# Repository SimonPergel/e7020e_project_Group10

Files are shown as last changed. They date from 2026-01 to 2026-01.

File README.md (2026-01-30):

# e7020e_project

# TOTP with automatic password input

## Members

- Gabriel Axheim Gustafsson (gabaxh-2@student.ltu.se)
- Patrik Wall (walpat-1@student.ltu.se)
- Simon Pergel (isoepe-1@student.ltu.se)

## High level specification
Our TOTP fob is designed to be able to automatically input the password calculated by behaving like a keyboard when you click the button once, holding the button down will instead make it behave like a usb memory thus allowing a user to insert a new secret onto the device.
- Button
  - Click: calculate & act as keyboard (enters password automatically)
  - Hold: allow insertion of secrets
- Display
  - If button was clicked show password (battery)
  - If button was clicked send password (usb)
    - Show successful message when password was "sent"
  - If button was held & connected to USB
    - Restart USB connection & act as a USB memory
    - Allow a user to store new secret

### Hardware Features
- 1x Real time clock (32kHz crystal)
- 1x Button
- 1x USB connector
- 1x Display
- 1x Battery connector (5V)

### Software Features
- Allow setting & getting time
- Set shared secret
- Encrypt secret
- Deep sleep (1mA during idle)

### Additional features
- Battery powered while not connected to USB
- Allowing the TOTP to switch between different behaviour
  - Might need to terminate USB connection for this to work
  - Acting as a keyboard
  - Acting as a USB memory
- *LED displaying remaining battery

Features starting with * might be included depending on difficulty and time required to complete said feature

## Grading
- Gabriel
  - Expected contributions towards grade 4?
  - Expected contributions towards grade 5?

- Simon
  - Expected contributions towards grade 4?
  - Expected contributions towards grade 5?
 
- Patrik
  - Expected contributions towards grade 4?
  - Expected contributions towards grade 5?

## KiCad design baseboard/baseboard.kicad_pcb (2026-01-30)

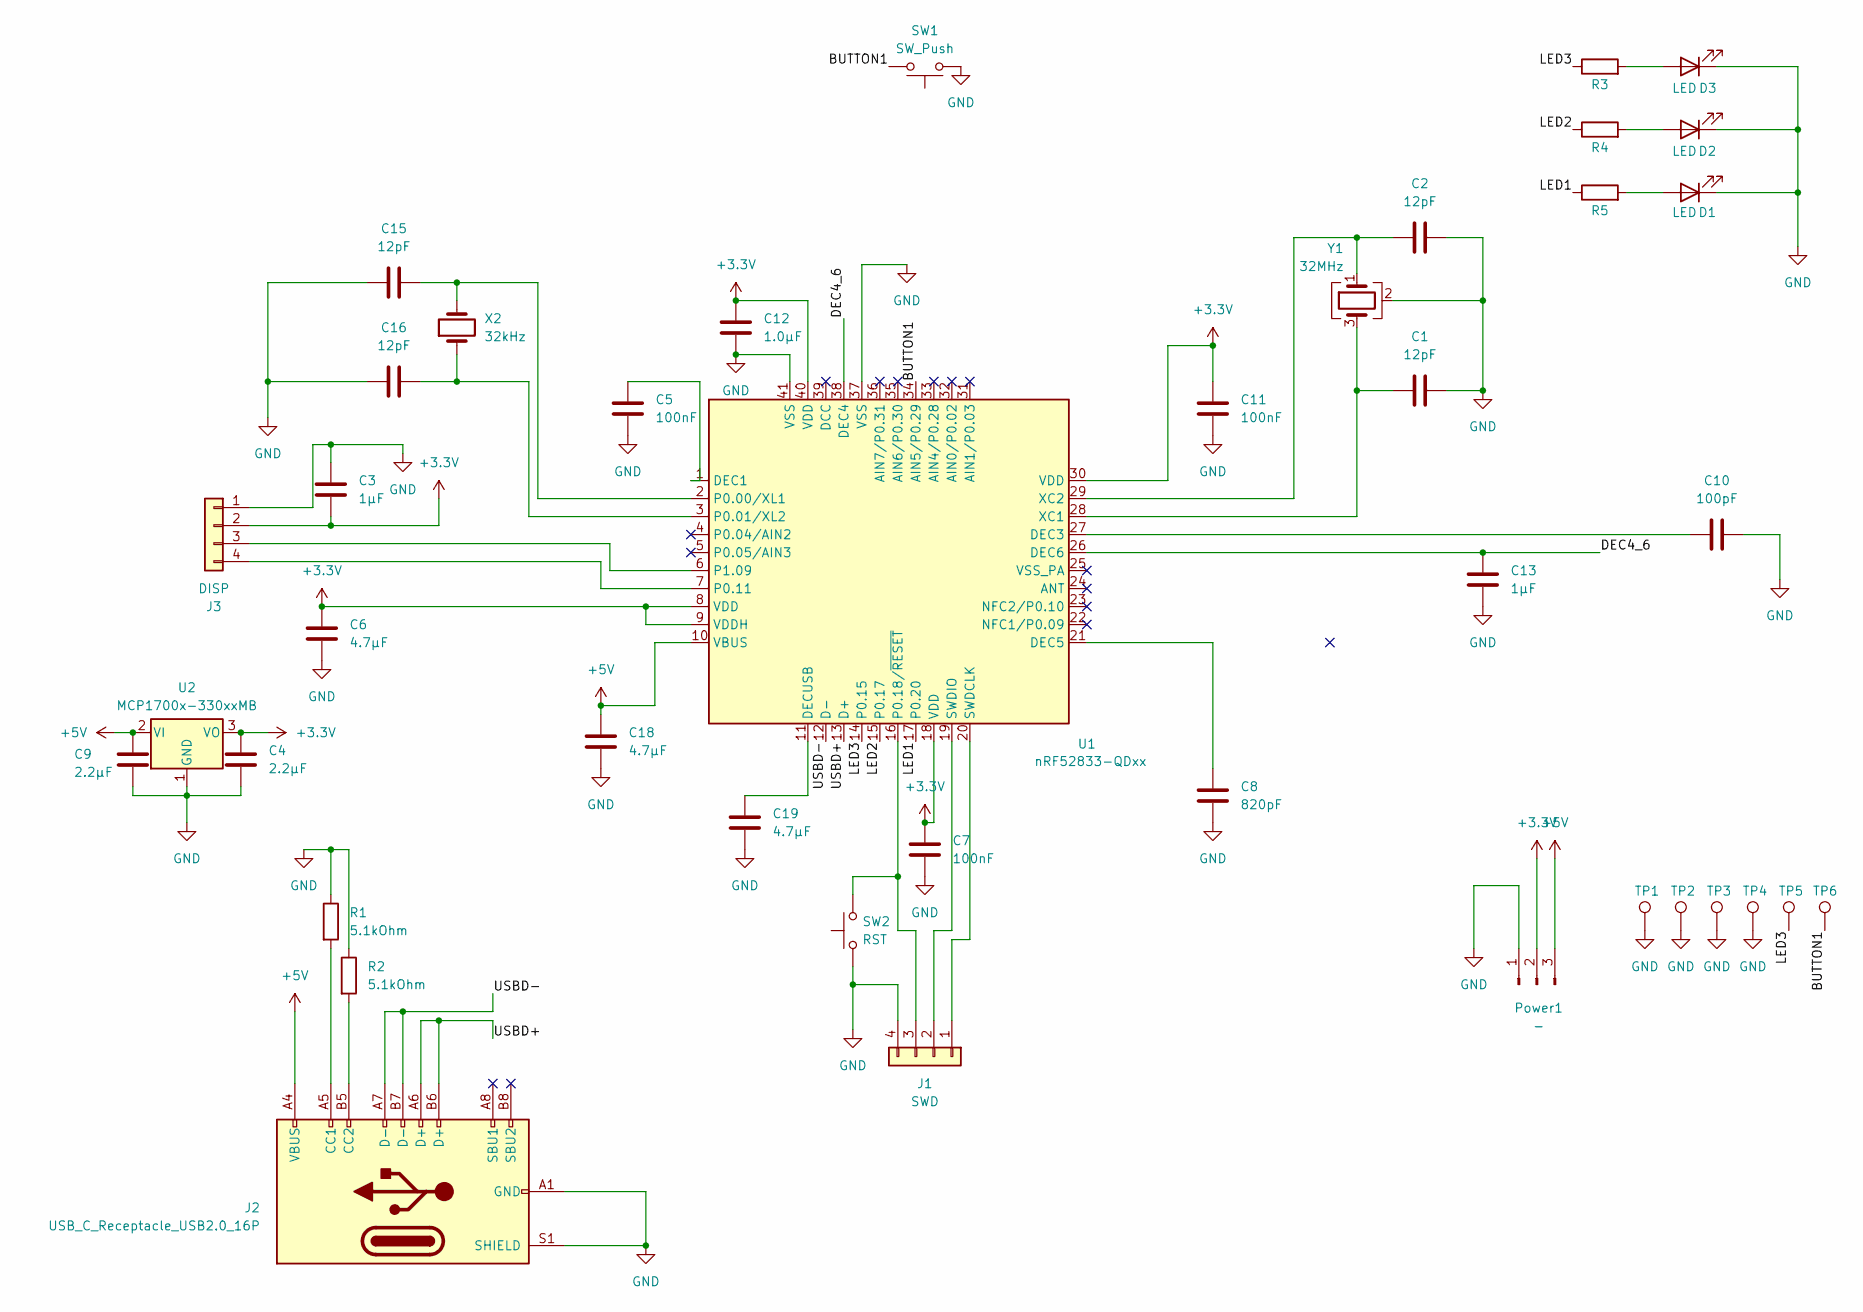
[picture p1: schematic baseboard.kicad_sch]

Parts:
C1, C2, C15, C16: 12pF; C_0603_1608Metric
C3, C13: 1µF; C_0603_1608Metric
C4, C9: 2.2µF; C_0603_1608Metric
C5, C7, C11: 100nF; C_0603_1608Metric
C6, C18, C19: 4.7µF; C_0603_1608Metric
C8: 820pF; C_0603_1608Metric
C10: 100pF; C_0603_1608Metric
C12: 1.0µF; C_0603_1608Metric
D1, D2, D3: LED; LED_0805_2012Metric
J1: SWD; PinHeader_1x04_P2.54mm_Vertical
J2: USB_C_Receptacle_USB2.0_16P; USB_C_Receptacle_GCT_USB4105-xx-A_16P_TopMnt_Horizontal
J3: DISP; PinHeader_1x04_P2.54mm_Vertical
Power1: -; PinHeader_1x03_P2.54mm_Vertical
R1, R2: 5.1kOhm; R_0603_1608Metric
R3, R4, R5: 330Ohm; R_0603_1608Metric
SW1: SW_Push; SW_PUSH_6mm_H9.5mm
SW2: RST; SW_PUSH_6mm_H9.5mm
TP1, TP2, TP3, TP4, TP5, TP6: TestPoint_THTPad_1.5x1.5mm_Drill0.8mm
U1: nRF52833-QDxx; QFN-40-1EP_5x5mm_P0.4mm_EP3.6x3.6mm
U2: MCP1700x-330xxMB; SOT-89-3
X2: 32kHz; Crystal_AT310_D3.0mm_L10.0mm_Horizontal
Y1: 32MHz; Crystal_SMD_3225-4Pin_3.2x2.5mm_HandSoldering

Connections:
+3.3V: C3.2, C4.1, C6.1, C7.1, C11.1, C12.1, J3.2, Power1.2, U1.8 (VDD), U1.9 (VDDH), U1.18 (VDD), U1.30 (VDD), U1.40 (VDD), U2.3 (VO)
+5V: C9.1, C18.1, J2.A4 (VBUS), J2.A9 (VBUS), J2.B4 (VBUS), J2.B9 (VBUS), Power1.3, U1.10 (VBUS), U2.2 (VI)
/BUTTON1: SW1.2, TP6.1, U1.34 (AIN5/P0.29)
/DEC4_6: C13.2, U1.26 (DEC6), U1.38 (DEC4)
/LED1: R5.1, U1.17 (P0.20)
/LED2: R4.1, U1.15 (P0.17)
/LED3: R3.1, TP5.1, U1.14 (P0.15)
/USBD+: J2.A6 (D+), J2.B6 (D+), U1.13 (D+)
/USBD-: J2.A7 (D-), J2.B7 (D-), U1.12 (D-)
GND: C1.2, C2.2, C3.1, C4.2, C5.2, C6.2, C7.2, C8.2, C9.2, C10.2, C11.2, C12.2, C13.1, C15.1, C16.1, C18.2, C19.2, D1.1 (K), D2.1 (K), D3.1 (K), J1.4, J2.A1 (GND), J2.A12 (GND), J2.B1 (GND), J2.B12 (GND), J2.S1 (SHIELD), J3.1, Power1.1, R1.1, R2.1, SW1.1, SW2.1, TP1.1, TP2.1, TP3.1, TP4.1, U1.37 (VSS), U1.41 (VSS), U2.1 (GND), Y1.2 (G), Y1.4 (G)
unnamed: D1.2 (A), R5.2
unnamed: D2.2 (A), R4.2
unnamed: D3.2 (A), R3.2
unnamed: J1.1, U1.20 (SWDCLK)
unnamed: J1.2, U1.19 (SWDIO)
unnamed: J1.3, SW2.2, U1.16 (P0.18/~RESET)
unnamed: J2.A5 (CC1), R1.2
unnamed: J2.B5 (CC2), R2.2
unnamed: J3.3, U1.6 (P1.09)
unnamed: J3.4, U1.7 (P0.11)
unnamed: C5.1, U1.1 (DEC1)
unnamed: C10.1, U1.27 (DEC3)
unnamed: C8.1, U1.21 (DEC5)
unnamed: C19.1, U1.11 (DECUSB)
unnamed: C15.2, U1.2 (P0.00/XL1), X2.2
unnamed: C16.2, U1.3 (P0.01/XL2), X2.1
unnamed: C1.1, U1.28 (XC1), Y1.3
unnamed: C2.1, U1.29 (XC2), Y1.1

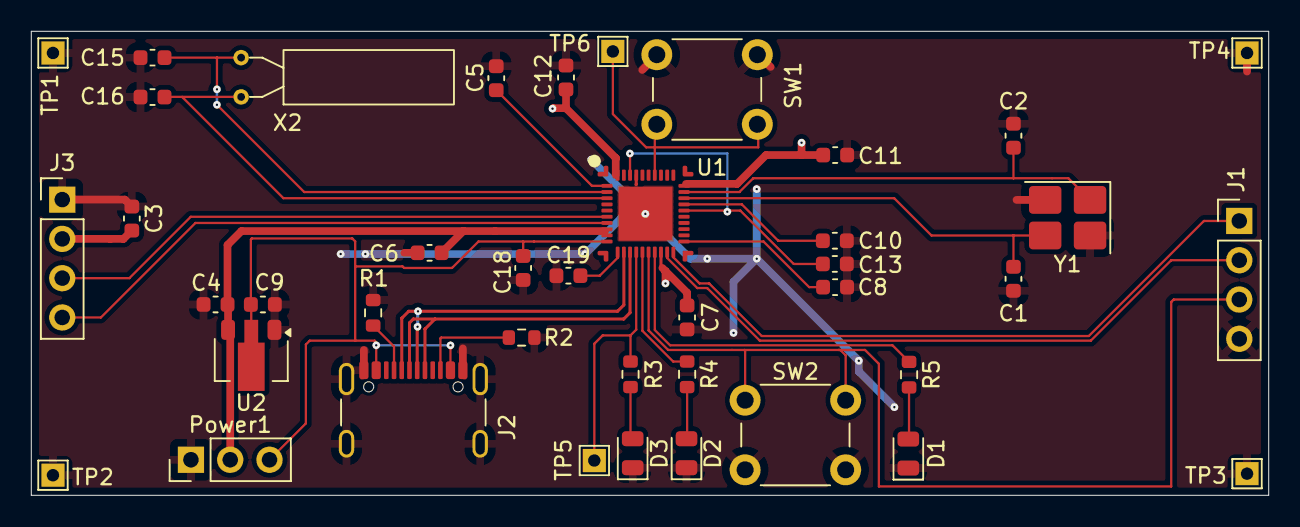
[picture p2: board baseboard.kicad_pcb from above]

Board: 4 copper layers, 80.0 x 30.0 mm, 41 parts (0 on the bottom side), 28 nets.
